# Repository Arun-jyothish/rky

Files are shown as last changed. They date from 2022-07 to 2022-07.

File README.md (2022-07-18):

# RKY 

## Multipurpose Remote Key Fob

## Functions
* Remote access ( start,horn,disable --car,bike,room)
* Display Informations, recieved from NRF24L01,WiFi
* Rolling codes
* buzzer
* vibration while near field detection
* compass directions
* preset commands in key, whenever a source device detect, it apply the commands
* disply time 

## Features
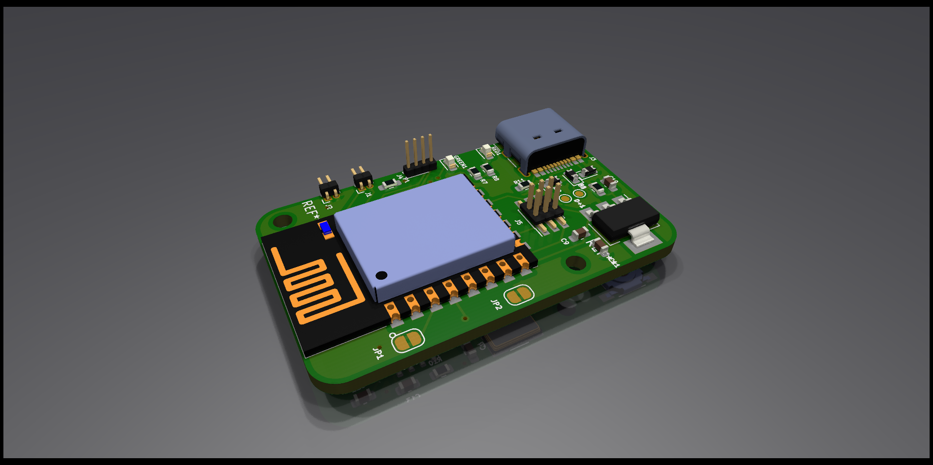
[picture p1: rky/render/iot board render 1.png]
render image 1

## Specifications
* Vibrator Motor
* LED BLINK
* OLED display
* WiFi connectivity
* RF transmitter
* NRF24L01
* 

~~~mermaid
graph TD
power--> ESP8266
NRF24L01--> ESP8266
OLED--> ESP8266
UART --> ESP8266
power-->NRF24L01
power-->OLED
power-->UART

~~~
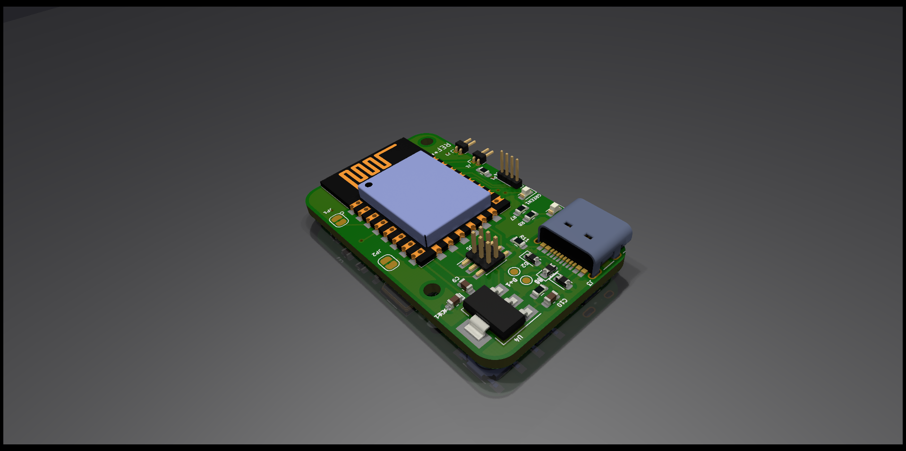
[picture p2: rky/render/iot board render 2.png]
render image 1


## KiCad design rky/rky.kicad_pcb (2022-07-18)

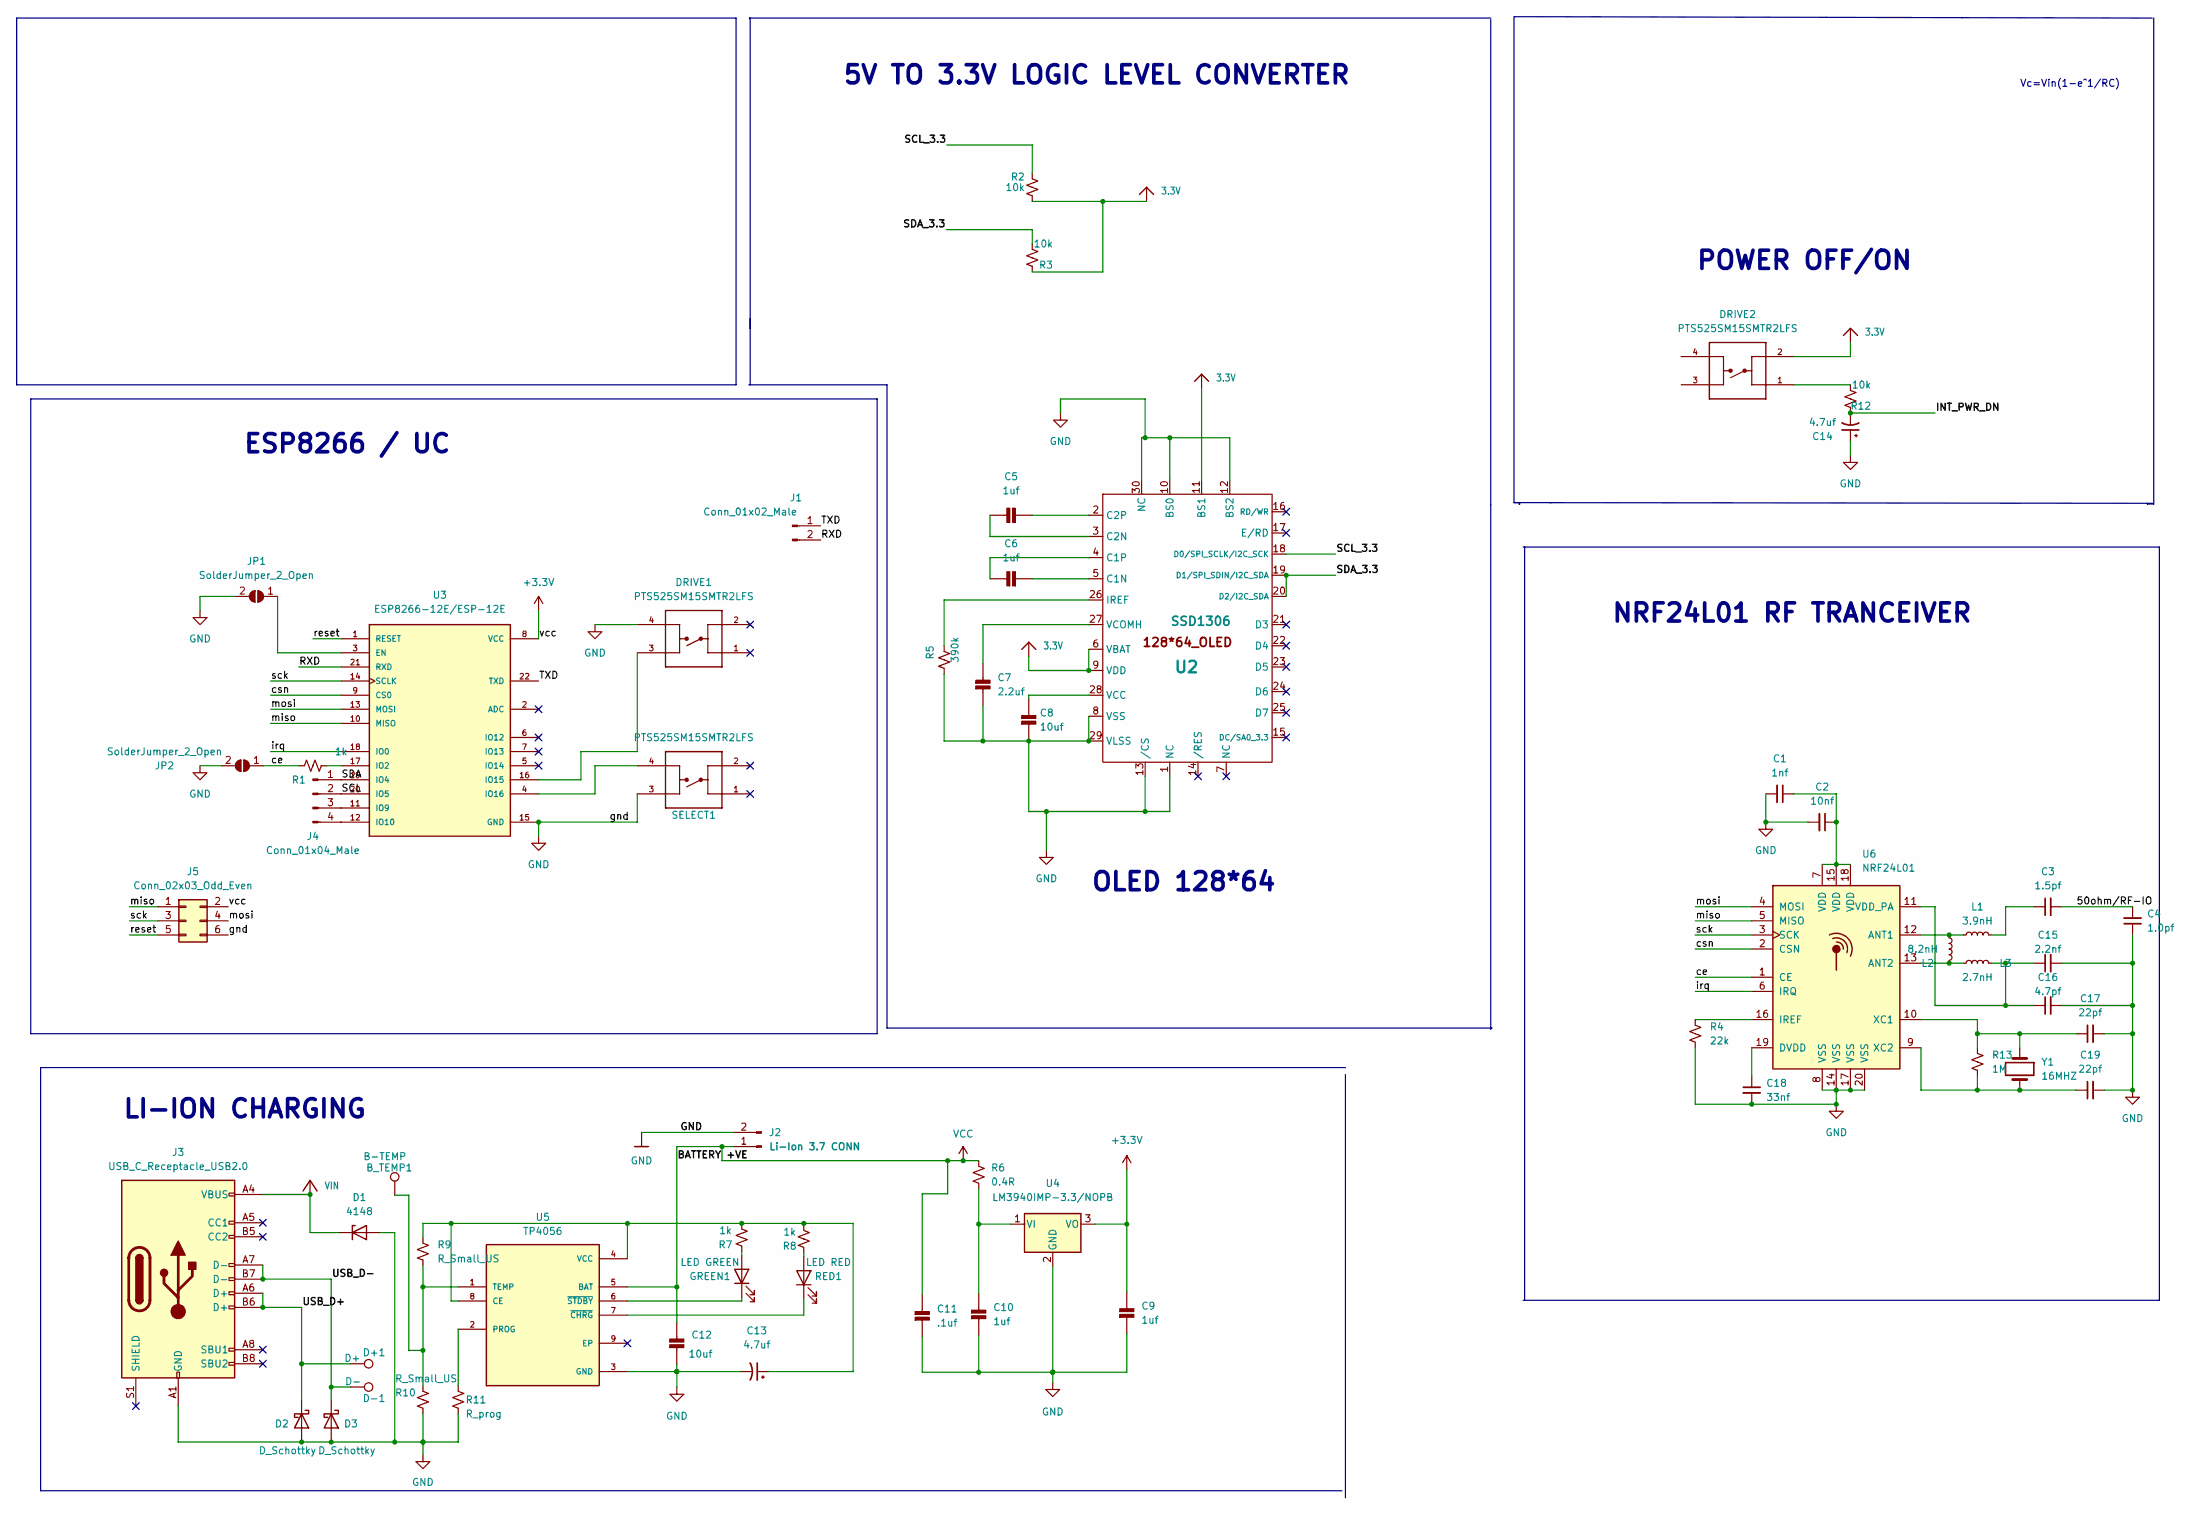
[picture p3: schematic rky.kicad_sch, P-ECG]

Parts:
B_TEMP1: B-TEMP; TestPoint_Pad_D1.0mm
C1: 1nf; C_0603_1608Metric_Pad1.08x0.95mm_HandSolder
C2: 10nf; C_0603_1608Metric_Pad1.08x0.95mm_HandSolder
C3: 1.5pf; C_0603_1608Metric_Pad1.08x0.95mm_HandSolder
C4: 1.0pf; C_0603_1608Metric_Pad1.08x0.95mm_HandSolder
C5, C6, C9, C10: 1uf; C_0603_1608Metric; JLC PCB PART NUMBER C2168630
C7: 2.2uf; C_0603_1608Metric; JLC PCB PART NUMBER C2858007
C8, C12: 10uf; C_0603_1608Metric; JLC PCB PART NUMBER C2167337
C11: .1uf; C_0603_1608Metric; JLC PCB PART NUMBER C2237744
C13, C14: 4.7uf; C_0603_1608Metric; JLC PCB PART NUMBER C2204347
C15: 2.2nf; C_0603_1608Metric_Pad1.08x0.95mm_HandSolder
C16: 4.7pf; C_0603_1608Metric_Pad1.08x0.95mm_HandSolder
C17, C19: 22pf; C_0603_1608Metric_Pad1.08x0.95mm_HandSolder
C18: 33nf; C_0603_1608Metric_Pad1.08x0.95mm_HandSolder
D1: 4148; D_0603_1608Metric; JLC PCB PART NUMBER C109002
D2, D3: D_Schottky; D_0603_1608Metric; JLC PCB PART NUMBER C143772
D+1: D+; TestPoint_Pad_D1.0mm
D-1: D-; TestPoint_Pad_D1.0mm
DRIVE1, DRIVE2: PTS525SM15SMTR2LFS; SW_PTS525SM15SMTR2LFS; PARTREV NA; JLC PCB PART NUMBER C221856
GREEN1: LED GREEN; LED_0603_1608Metric; JLC PCB PART NUMBER C2917809
J1: Conn_01x02_Male; PinHeader_1x02_P1.00mm_Horizontal
J2: Li-Ion 3.7 CONN; PinHeader_1x02_P1.00mm_Horizontal
J3: USB_C_Receptacle_USB2.0; USB_C_Receptacle_HRO_TYPE-C-31-M-12; JLC PCB PART NUMBER C2927026
J4: Conn_01x04_Male; PinHeader_1x04_P1.00mm_Vertical
J5: Conn_02x03_Odd_Even; PinHeader_2x03_P1.27mm_Vertical_SMD
JP1, JP2: SolderJumper_2_Open; SolderJumper-2_P1.3mm_Bridged2Bar_RoundedPad1.0x1.5mm
L1: 3.9nH
L2: 8.2nH; 8.2nG
L3: 2.7nH
R1: 1k; R_0603_1608Metric_Pad0.98x0.95mm_HandSolder
R2, R3, R12: 10k; R_0603_1608Metric; JLC PCB PART NUMBER C2930027
R4: 22k; R_0603_1608Metric_Pad0.98x0.95mm_HandSolder
R5: 390k; R_0603_1608Metric; JLC PCB PART NUMBER C304747
R6: 0.4R; R_0603_1608Metric; JLC PCB PART NUMBER C2907088
R7, R8: 1k; R_0603_1608Metric; JLC PCB PART NUMBER C2913953
R9, R10: R_Small_US; R_0603_1608Metric
R11: R_prog; R_0603_1608Metric
R13: 1M; R_0603_1608Metric_Pad0.98x0.95mm_HandSolder
RED1: LED RED; LED_0603_1608Metric; JLC PCB PART NUMBER C2917808
SELECT1: PTS525SM15SMTR2LFS; SW_PTS525SM15SMTR2LFS; PARTREV NA; JLC PCB PART NUMBER C221856
U2: SSD1306; OLED-128O064D; JLC PCB PART NUMBER C2890600
U3: ESP8266-12E/ESP-12E; XCVR_ESP8266-12E_ESP-12E
U4: LM3940IMP-3.3/NOPB; SOT-223; JLC PCB PART NUMBER C140319
U5: TP4056; SO-8_5.3x6.2mm_P1.27mm; JLC PCB PART NUMBER C725790
U6: NRF24L01; QFN-20-1EP_4x4mm_P0.5mm_EP2.5x2.5mm
Y1: 16MHZ; Crystal_SMD_0603-4Pin_6.0x3.5mm

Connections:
3.3V: DRIVE2.2, R2.1, R3.1, U2.6 (VBAT), U2.9 (VDD), U2.11 (BS1)
+3V3: C9.1, J5.2, U3.8 (VCC), U4.3 (VO)
/50ohm/RF-IO: C3.2, C4.2
/INT_PWR_DN: C14.2, R12.1
/RXD: J1.2, U3.21 (RXD)
/SCL: J4.2, U3.20 (IO5)
/SCL_3.3: R2.2, U2.18 (D0/SPI_SCLK/I2C_SCK)
/SDA: J4.1, U3.19 (IO4)
/SDA_3.3: R3.2, U2.19 (D1/SPI_SDIN/I2C_SDA), U2.20 (D2/I2C_SDA)
/TXD: J1.1, U3.22 (TXD)
/USB_D+: D2.1 (K), D+1.1, J3.A6 (D+), J3.B6 (D+)
/USB_D-: D3.1 (K), D-1.1, J3.A7 (D-), J3.B7 (D-)
/ce: JP2.1 (A), R1.1, U6.1 (CE)
/csn: U3.9 (CS0), U6.2 (CSN)
/irq: U3.18 (IO0), U6.6 (IRQ)
/miso: J5.1, U3.10 (MISO), U6.5 (MISO)
/mosi: J5.4, U3.13 (MOSI), U6.4 (MOSI)
/reset: J5.5, U3.1 (RESET)
/sck: J5.3, U3.14 (SCLK), U6.3 (SCK)
GND: C1.2, C2.2, C4.1, C7.2, C8.2, C9.2, C10.2, C11.2, C14.1, C15.2, C16.2, C17.2, C18.2, C19.2, D1.2 (A), D2.2 (A), D3.2 (A), DRIVE1.4, J2.2, J3.A1 (GND), J3.A12 (GND), J3.B1 (GND), J3.B12 (GND), J5.6, JP1.2 (B), JP2.2 (B), R4.2, R5.2, R10.1, R11.1, SELECT1.3, U2.1 (NC), U2.8 (VSS), U2.10 (BS0), U2.12 (BS2), U2.13 (/CS), U2.29 (VLSS), U2.30 (NC), U3.15 (GND), U4.2 (GND), U6.8 (VSS), U6.14 (VSS), U6.17 (VSS), U6.20 (VSS)
unnamed: B_TEMP1.1, R9.2, R10.2, U5.1 (TEMP)
unnamed: C1.1, C2.1, U6.7 (VDD), U6.15 (VDD), U6.18 (VDD)
unnamed: C3.1, L1.2
unnamed: C5.1, U2.3 (C2N)
unnamed: C5.2, U2.2 (C2P)
unnamed: C6.1, U2.4 (C1P)
unnamed: C6.2, U2.5 (C1N)
unnamed: C7.1, U2.27 (VCOMH)
unnamed: C8.1, U2.28 (VCC)
unnamed: C10.1, R6.2, U4.1 (VI)
unnamed: C12.2, C13.2, U5.3 (GND)
unnamed: C13.1, R7.2, R8.2, R9.1, U5.4 (VCC), U5.8 (CE)
unnamed: C15.1, C16.1, L3.2, U6.11 (VDD_PA)
unnamed: C17.1, R13.1, U6.10 (XC1), Y1.1
unnamed: C18.1, U6.19 (DVDD)
unnamed: C19.1, R13.2, U6.9 (XC2), Y1.2
unnamed: DRIVE1.3, U3.16 (IO15)
unnamed: DRIVE2.1, R12.2
unnamed: GREEN1.1 (K), U5.6 (~STDBY)
unnamed: GREEN1.2 (A), R7.1
unnamed: J4.3, U3.11 (IO9)
unnamed: J4.4, U3.12 (IO10)
unnamed: JP1.1 (A), U3.3 (EN)
unnamed: L1.1, L2.1, U6.12 (ANT1)
unnamed: L2.2, L3.1, U6.13 (ANT2)
unnamed: R1.2, U3.17 (IO2)
unnamed: R4.1, U6.16 (IREF)
unnamed: R5.1, U2.26 (IREF)
unnamed: R8.1, RED1.2 (A)
unnamed: R11.2, U5.2 (PROG)
unnamed: RED1.1 (K), U5.7 (~CHRG)
unnamed: SELECT1.4, U3.4 (IO16)
VCC: C11.1, C12.1, J2.1, R6.1, U5.5 (BAT)
VIN: D1.1 (K), J3.A4 (VBUS), J3.A9 (VBUS), J3.B4 (VBUS), J3.B9 (VBUS)

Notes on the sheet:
POWER OFF/ON
ESP8266 / UC
NRF24L01 RF TRANCEIVER
OLED 128*64
Vc=Vin(1-e^1/RC)
LI-ION CHARGING
5V TO 3.3V LOGIC LEVEL CONVERTER

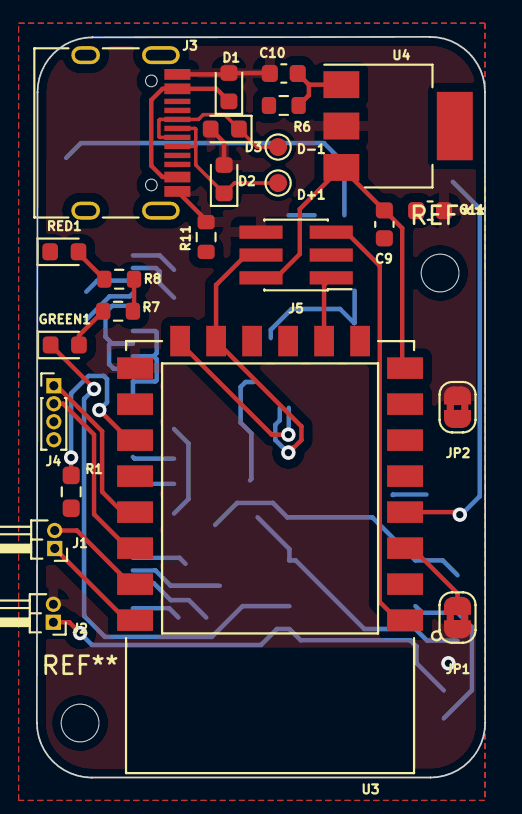
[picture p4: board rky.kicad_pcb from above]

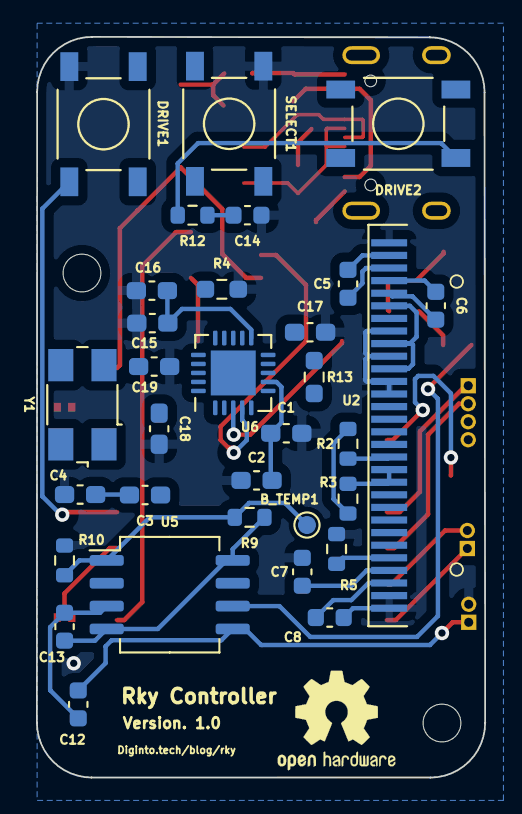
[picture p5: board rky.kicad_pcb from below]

Board: 2 copper layers, 24.9 x 41.1 mm, 56 parts (32 on the bottom side), 51 nets.

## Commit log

2022-06-10 rough pcb layout create
    [rky.kicad_pcb, rky.kicad_sch]
2022-06-11 schematic update
    [rky.kicad_pcb, rky.kicad_sch]
2022-07-02 remove cp2102
    new layout
    [rky.kicad_pcb]
2022-07-03 component place
    first touch component placement complete
    [rky.kicad_pcb, rky.kicad_sch]
2022-07-09 add render folder
    kicad 3d render image folder add
    [rky.kicad_pcb, rky.kicad_sch]
2022-07-18 update README
    add render images
    [rky.kicad_pcb]
